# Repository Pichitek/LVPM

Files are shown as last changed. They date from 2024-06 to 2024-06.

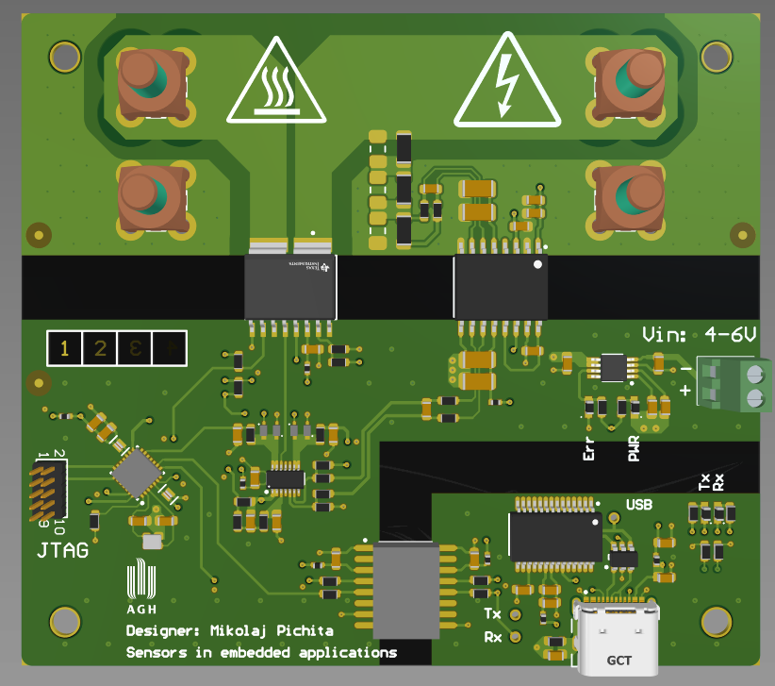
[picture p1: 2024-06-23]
photos/3D.png

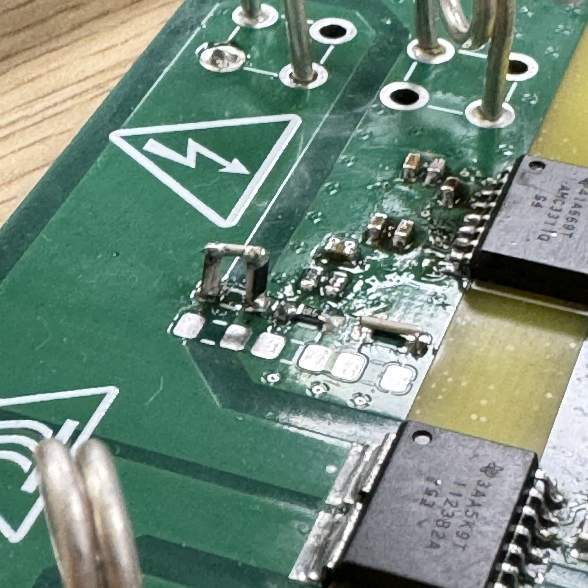
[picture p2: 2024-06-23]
photos/poprawiony_dzilnik.jpg

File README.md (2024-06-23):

# Low Voltage Power Measurement
Premise of the project for this class was to implement any sensor into working device. Our group decided that we would like to make power measurement device based on widely available Hall sensors.

schemat_blokowy

As seen on this block diagram, this project can serve as standalone device. It is capable of measuring current and voltage, acquiring data on STM32F0 microcontroller and transmitting this data over UART. Design provides two isolation barriers to make sure that any device which is connected to the LVMP will not be damaged.

This project consists of:
- PCB and schematic of LVPM
- firmware for the microcontoller
- desktop app for data visualization (https://github.com/arkadiuszrapacz/HalSensorApp)
- project presentations and report (written in polish)

zmonotwana_plyka

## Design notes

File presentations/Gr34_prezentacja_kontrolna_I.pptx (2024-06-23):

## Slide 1

Miernik mocy do zastosowań LV

Grupa nr 34: Paweł Pasierbek, Mikołaj Pichita, Arkadiusz Rapacz,
Tomasz Szydłak

18.03.2024

## Schemat blokowy

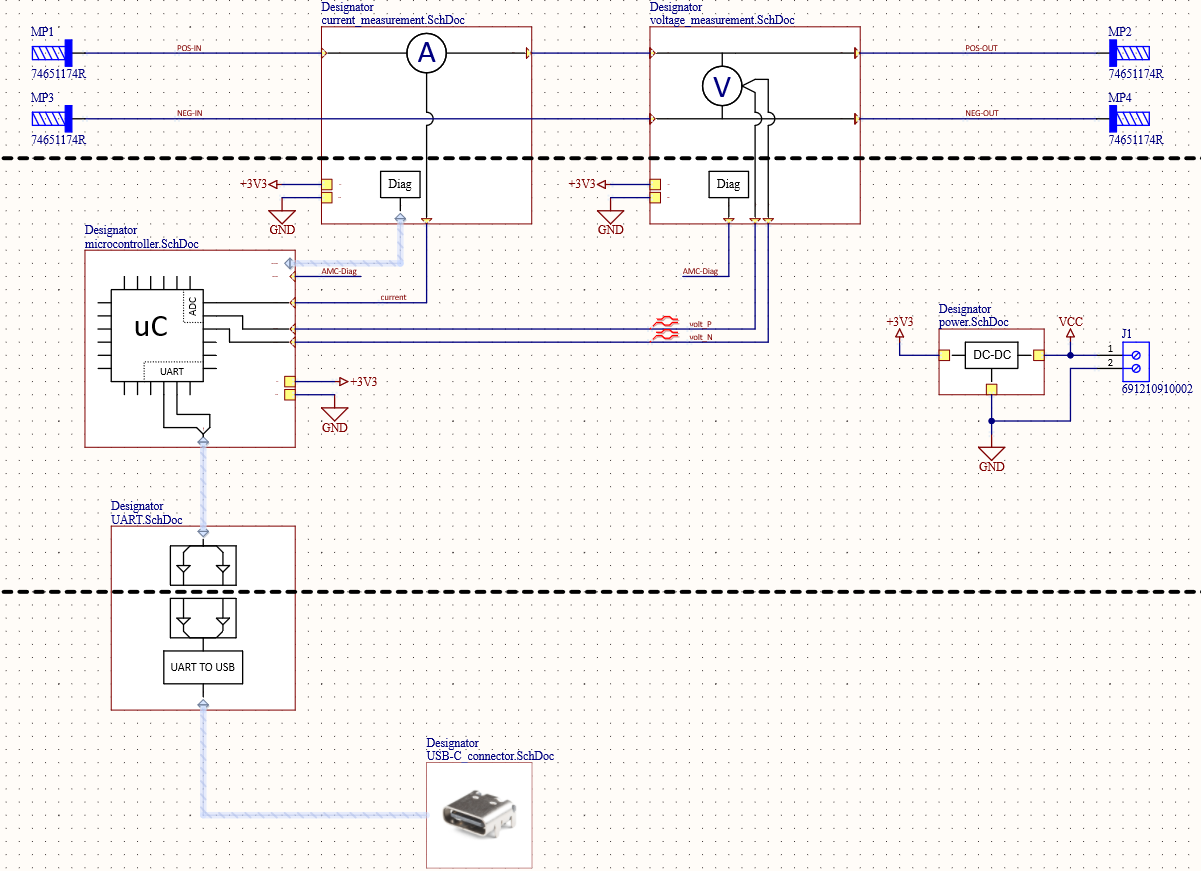
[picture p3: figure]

MIKOŁAJ

Rys. 1) Schemat blokowy

## Działanie sensora Halla

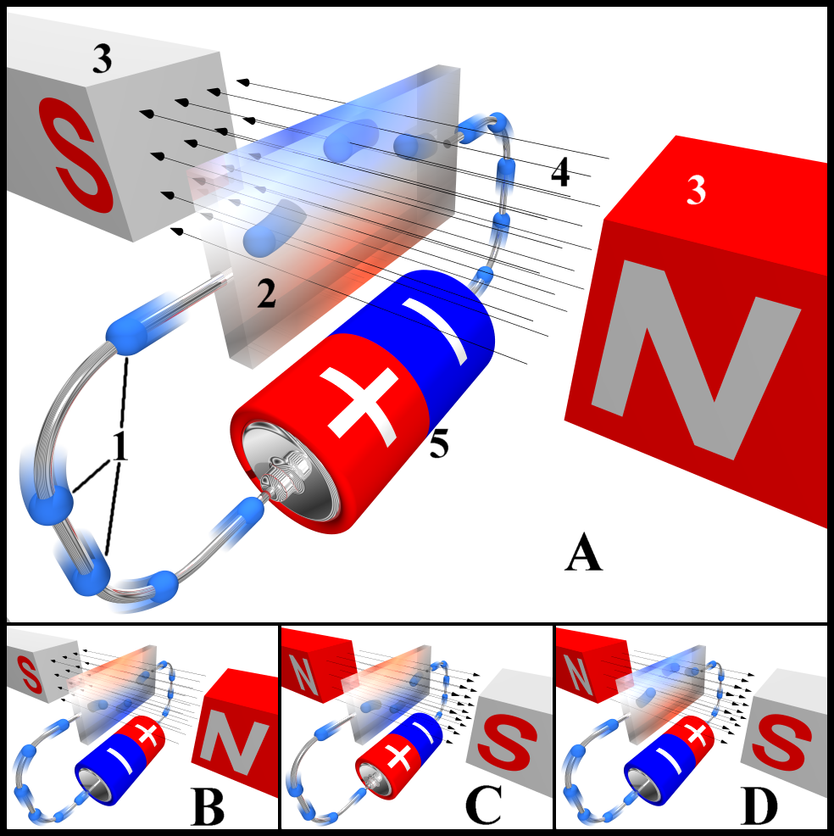
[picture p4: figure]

Rys. 2) Zobrazowanie efektu Halla

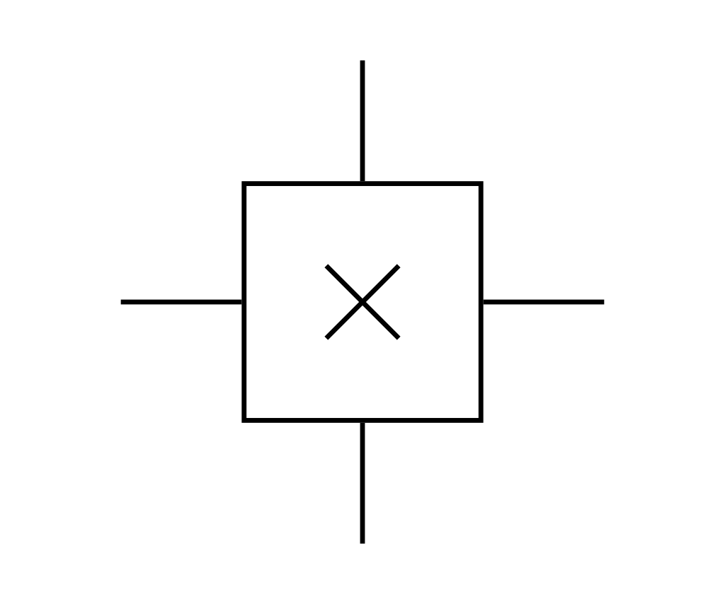
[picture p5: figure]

Rys. 3) Symbol hallotronu

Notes: Zjawisko polegające na wystąpieniu różnicy potencjałów w przewodniku, w którym płynie prąd elektryczny, gdy przewodnik znajduje się w poprzecznym do płynącego prądu polu magnetycznym. Ta różnica potencjałów, zwana napięciem Halla, pojawia się między płaszczyznami ograniczającymi przewodnik, prostopadle do płaszczyzny wyznaczanej przez kierunek prądu i wektor indukcji magnectycznej. Jest ona spowodowana działaniem siły Lorentza na ładunki poruszające się w polu magnetycznym.

## Sensor TMCS1123

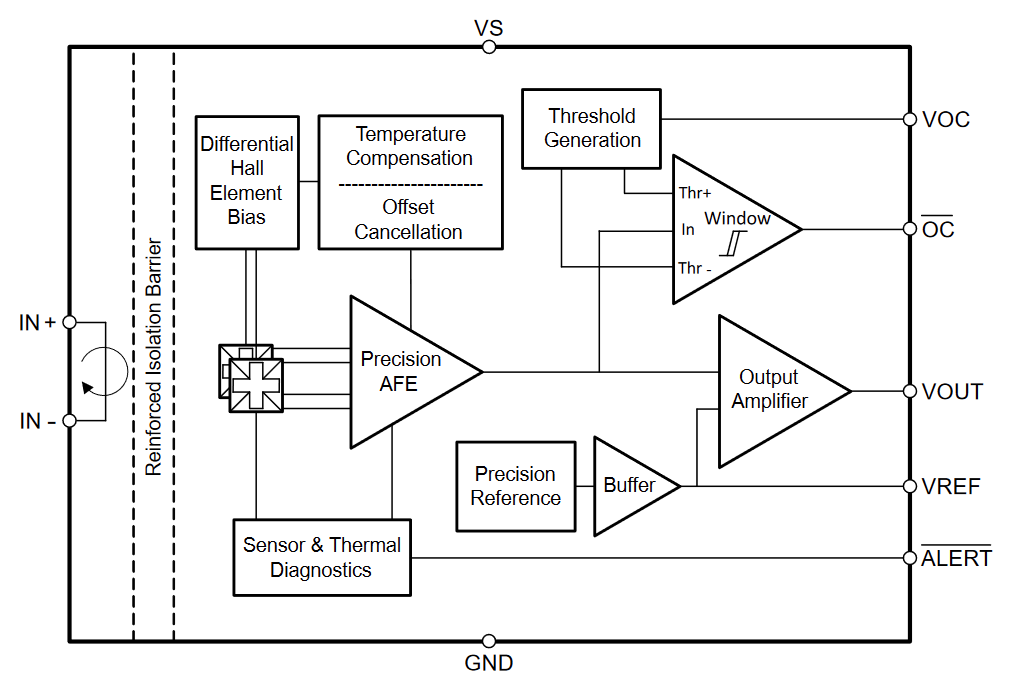
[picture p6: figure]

Rys. 4) Diagram funkcyjny sensora TMCS

## Zastosowanie mikroprocesora

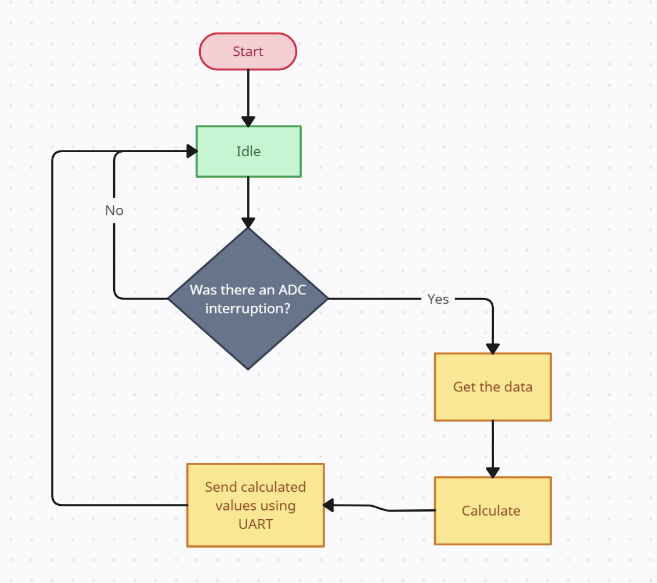
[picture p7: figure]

Rys. 5) Diagram blokowy przedstawiający działanie aplikacji

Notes: tuaj jakis flowchart jak bedzie działa uC w projekcie: idle -> przerwanie od ADC -> akwizycja danych -> obliczenie -> transmisja po UART

## Aplikacja na urządzenia stacjonarne

Dane do aplikacji dostarczane będą za pomocą protokołu UART.
Aplikacja służyć będzie do monitorowania wskazań wykorzystanego czujnika, a jej głównym założeniem w procesie realizacji będzie prostota obsługi oraz przejrzystość przedstawianych danych.

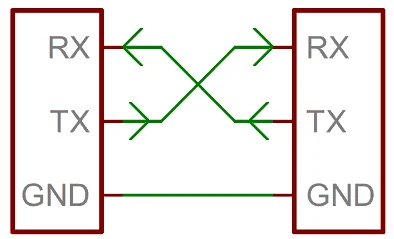
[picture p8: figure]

Rys. 6) Uproszczona wizualizacja protokołu komunikacyjnego UART

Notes: tutaj idk, nawet coś w paint naszkicowane jak ta apka będzie wyglądać POGLĄDOWO, ja bym dał 2 odczyty z ADC (prąd napięcie) wyliczana moc, wykres mocy w czasie który się będzie updateował, i jakieś dla diagnostyki informacje tymu: SENSOR GOOD na zielono

## Zakres odpowiedzialności w zespole

- Arek: Aplikacja służąca do parsowania danych na PC wraz z przejrzystym GUI
- Mikołaj: design systemu, projekt PCB, montaż, testowanie
- Tomek i Paweł: Programowanie mikroprocesora, obsługa sensorów, transfer danych na PC

## Dziękujemy za uwagę

## Bibliografia

Rys. 2) https://pl.wikipedia.org/wiki/Zjawisko_Halla#/media/Plik:Hall_effect.png
Rys. 3) https://pl.wikipedia.org/wiki/Hallotron#/media/Plik:Common_Hall_Sensor_Symbol.svg
Rys. 4) https://www.ti.com/lit/ds/symlink/tmcs1123.pdf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
Rys. 6) https://cdn.forbot.pl/blog/wp-content/uploads/2016/03/KursF4_7_25.png

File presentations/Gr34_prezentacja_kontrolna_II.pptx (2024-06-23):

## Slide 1

Miernik mocy do zastosowań LV

Grupa nr 34: Paweł Pasierbek, Mikołaj Pichita, Arkadiusz Rapacz,
Tomasz Szydłak

18.03.2024

## Schemat elektryczny

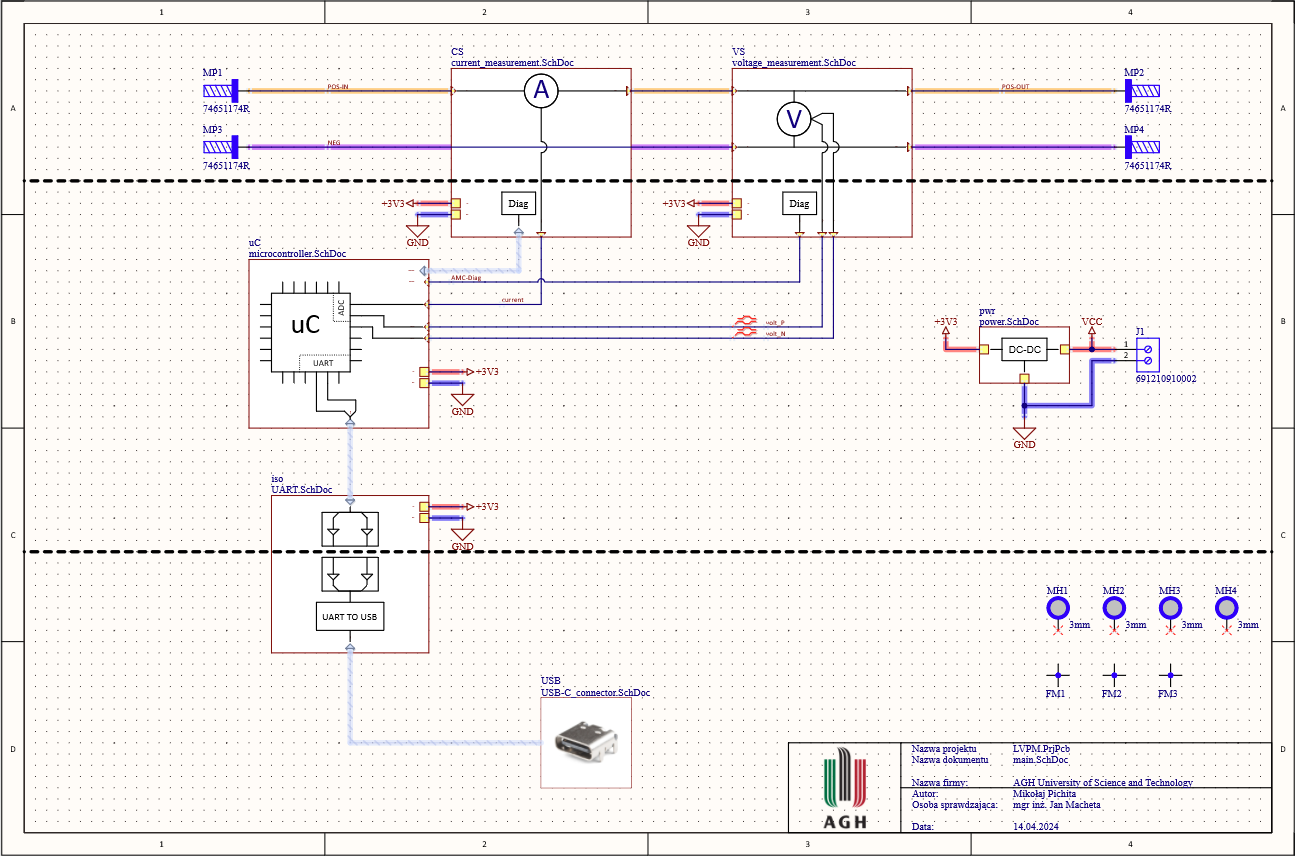
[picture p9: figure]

Rys. 1) Schemat blokowy

## Schemat elektryczny - pomiar prądu

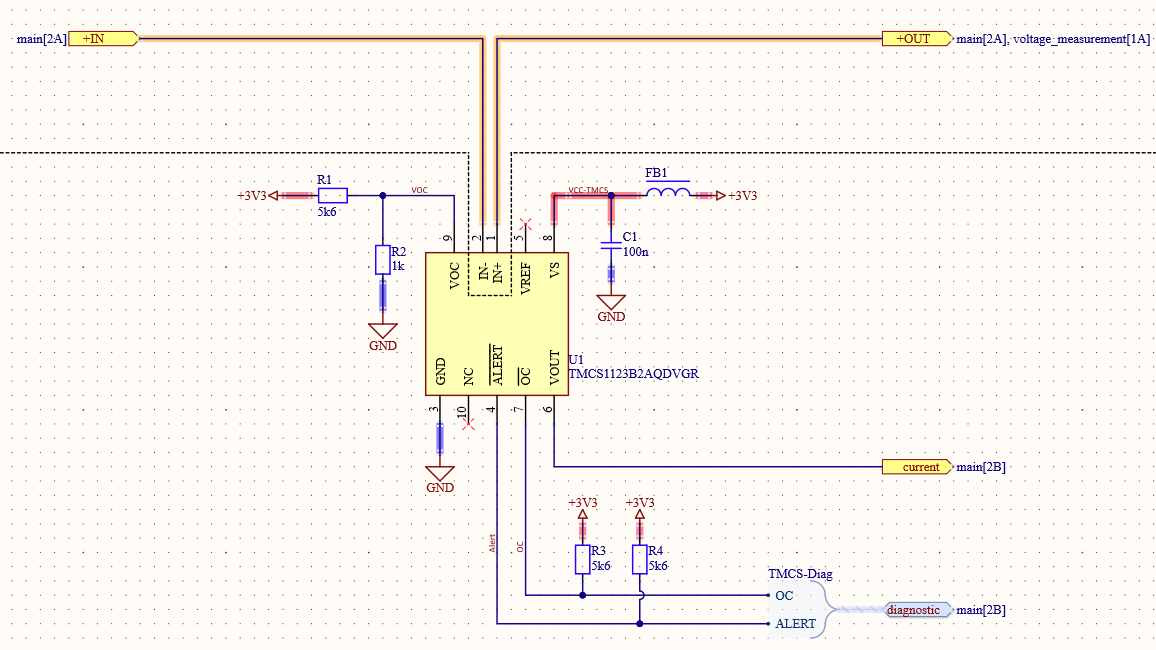
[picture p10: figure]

Rys. 2) Pomiar prądu wykorzystujący sensor Halla

## Schemat elektryczny - pomiar napięcia

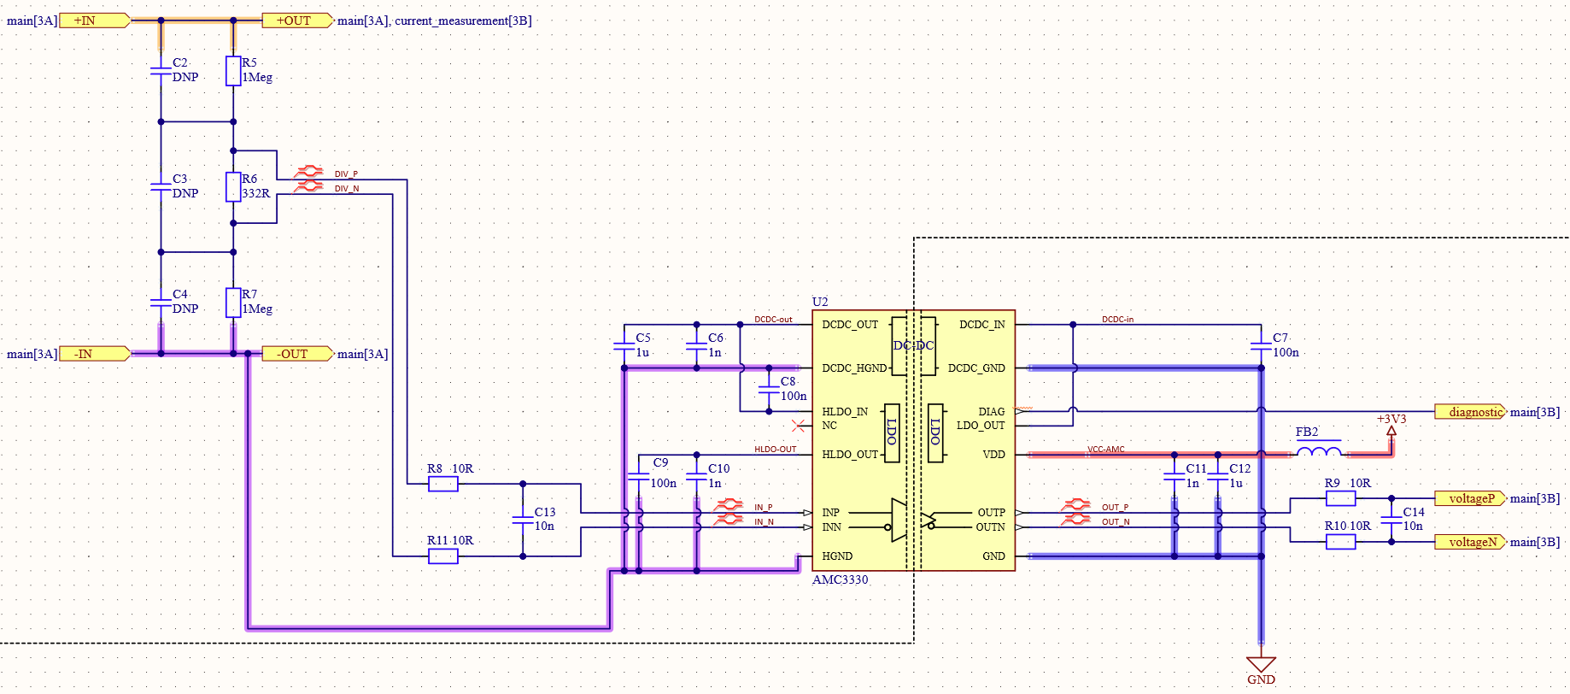
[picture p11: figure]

Rys. 3) Pomiar napięcia na izolowanym wzmacniaczu

## Płytka PCB

Rys. 4) Render 3D płytki PCB

## Płytka PCB

## Płytka PCB

## Płytka PCB

## Płytka PCB

## Oprogramowanie na mikrokontroler

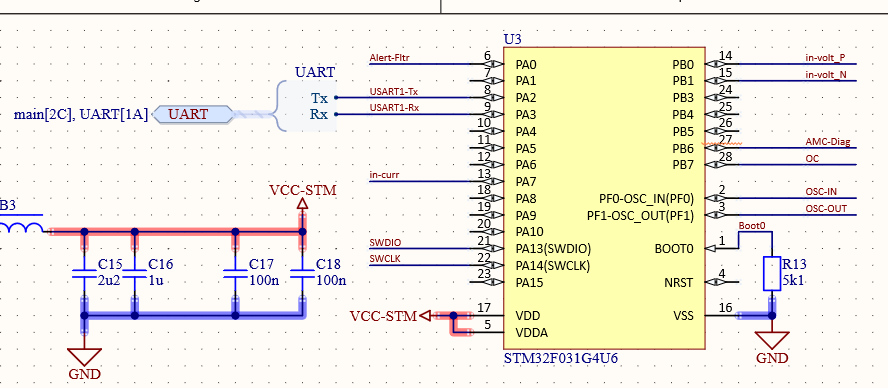
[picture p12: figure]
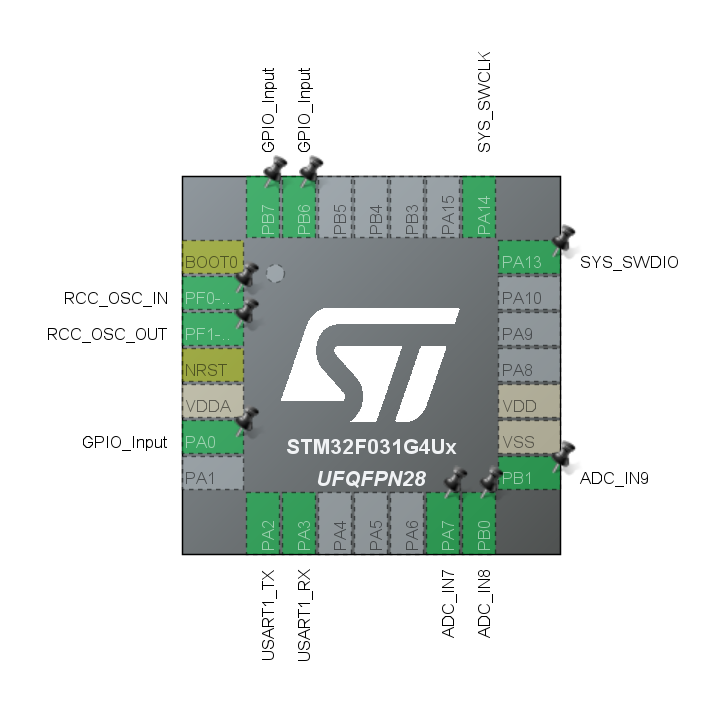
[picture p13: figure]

- in-curr - wejście analogowe do pomiaru prądu
- in-volt_P, in-volt_N - wejścia analogowe do pomiaru napięcia
- SWDIO, SWCLK - wejścia do programowania
- OSC-IN, OSC-OUT - wejścia do podłączenia oscylatora
- Alert-Fltr, OC, AMC-Diag - wejścia GPIO

## Aplikacja na urządzenia stacjonarne

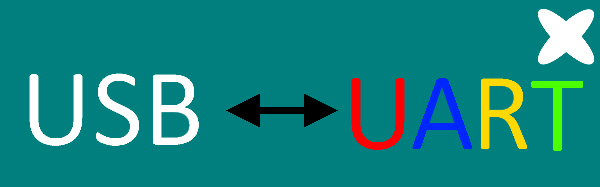
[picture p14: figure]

Język programowania: Python
Dodatkowe biblioteki: PySerial / PyQt5
Komunikacja: UART
Funkcjonalność: Przedstawienie odczytów z sensora Halla
Dodatkowo: Wizualizacja danych w czasie (wykres)

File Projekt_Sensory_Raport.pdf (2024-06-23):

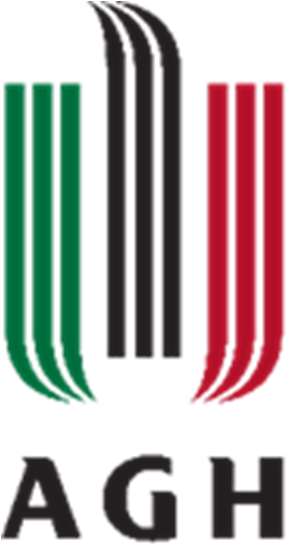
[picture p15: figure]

# AKADEMIA GÓRNICZO-HUTNICZA

# Raport z projektu

# Miernik mocy do zastosowań LV

# z przedmiotu

# Sensory w Aplikacjach Wbudowanych

# Elektronika i Telekomunikacja - Systemy Wbudowane, rok I studiów magisterskich

# Mikołaj Pichita Arkadiusz Rapacz Tomasz Szydłak

14.06.2024r

# Spis treści

1

## 1 Opis i założenie projektu

Celem projektu jest stworzenie urządzenia będącego w stanie mierzyć moc urządzeń pracujących w zakresie napięć LV (definicja napięcia Lov Voltage to mniej niż 1500VDC lub mniej niż 1000VAC RMS). Do realizacji takiego celu wymagane są: pomiar prądu, pomiar napięcia, akwizycja danych oraz ich transmisja do celu, celem może być urządzenie sterujące lub jak w naszym przypadku komputer osobisty.

### 1.1 Założenia projektowe i wysokopoziomowy opis projektu

Założenia projektowe odnośnie warstwy sprzętowej

- Pomiar prądu realizowany przy pomocy sensora Halla.
- Pomiar napięcia realizowany przy pomocy izolowanego wzmacniacza operacyjnego oraz wysokoimpedancyjnego dzielnika napięcia.
- Izolacja części wysokonapięciowej do sekcji niskonapięciowej.
- Dodatkowa warstwa izolacji pomiędzy sekcją niskonapięciową a sekcją komunikacyjną.
- Komunikacja z komputerem osobistym realizowana przy pomocy protokołu USB.

Założenia projektowe odnośnie warstwy oprogramowania

- Akwizycja danych za pomocą wbudowanego przetwornika ADC w mikrokontrolera.
- Transmisja danych przy pomocy protokołu UART.
- Odczytywanie danych diagnostycznych przy pomocy pinów GPIO.
- Uśrednianie pomiarów.
- Stworzenie "pakietu" danych, który będzie łatwy do interpretacji przez aplikację na komputery osobiste.
- Stworzenie aplikacji na komputery osobiste do odczytywania danych.

### 1.2 Podział odpowiedzialności

- Mikołaj - projekt wysokopoziomowy, projekt schematu oraz PCB, montaż, testowanie
- Arkadiusz - utworzenie aplikacji desktopowej odczytującej dane na porcie szeregowym
- Tomasz - programowanie mikrokontrolera, obliczanie wartości i testy oprogramowania

## 2 Sprzęt

### 2.1 Wybór komponentów

Opis wykorzystanych komponentów oraz uzasadnienie wyboru.

2

- Sensor Halla TMCS1123 - wzmocniona izolacja na poziomie 1.3kV, szeroki zakres pomiarowy, prostota w integracji
- Izolowany wzmacniacz operacyjny AMC3330 - wzmocniona izolacja na poziomie 1.7kV, wbudowana przetwornica DC-DC, wyjście różnicowe
- Mikrokontroler STM32F0 - prosta architektura, mały footprint, 12bitowe przetworniki ADC
- Liniowy regulator napięcia LP3997 - prąd wyjścia 250mA, niskie napięcie spadkowe na regulatorze, stałe wyjście 3.3V
- Izolator cyfrowy Si8621 - duża przepustowość, dwa kanały(jeden sygnału nadającego, drugi odbierającego), możliwość zasilenia zarówno 3.3V jak i 5V
- Konwerter UART→USB FT232 - standardowe rozwiązanie w przemyśle
- Wzmacniacz operacyjny TLV9004 - mały footprint, cztery kanały

Pozostałe komponenty wykorzystane w projekcie są elementami pasywnymi. W przypadku doboru rezystorów zwracano uwagę na dokładność rezystancji w kluczowych elementach, takich jak dzielniki napięcia, oraz na maksymalną moc jaką w stanie są one wytrzymać. Kondensatory dobierano tak aby klasyfikacja napięciowa danego kondensatora była co najmniej dwukrotnie większa od spodziewanego napięcia w danym węźle. Dodatkowo przy mikrokontrolerze zastosowano kondensatory w obudowie 0204 minimalizując impedancję pasożytniczą elementu.

3

### 2.2 Opis schematu

Projekt płytki PCB został wykonany w programie Altium Designer 24.

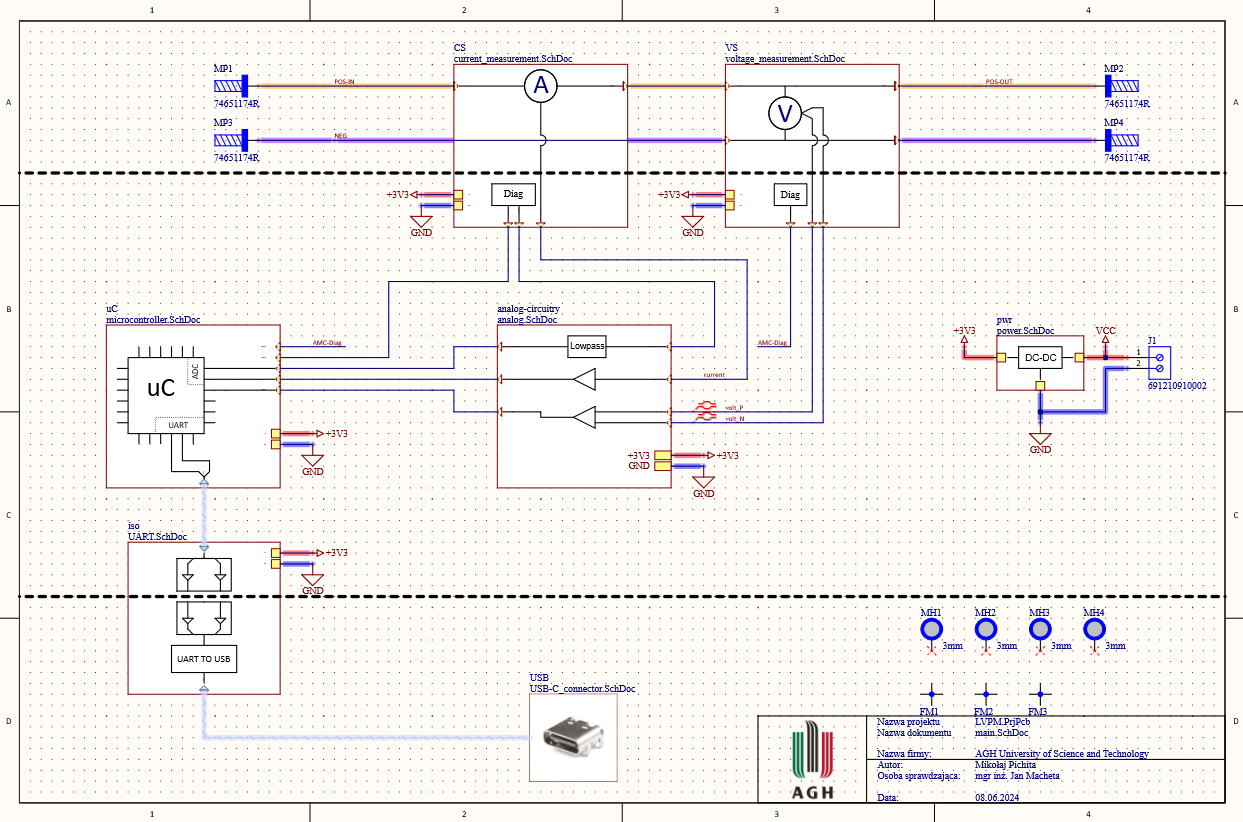
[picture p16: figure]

Rysunek 1: Schemat blokowy urządzenia po zaimplementowanych poprawkach

Schemat blokowy składa się łącznie z siedmiu bloków funkcyjnych:

- pomiar prądu
- pomiar napięcia
- front-end analogowy dla sygnałów pochodzących z sensorów
- mikrokontroler
- izolator cyfrowy i konwerter UART→USB
- złącze USB-C
- zasilanie

4

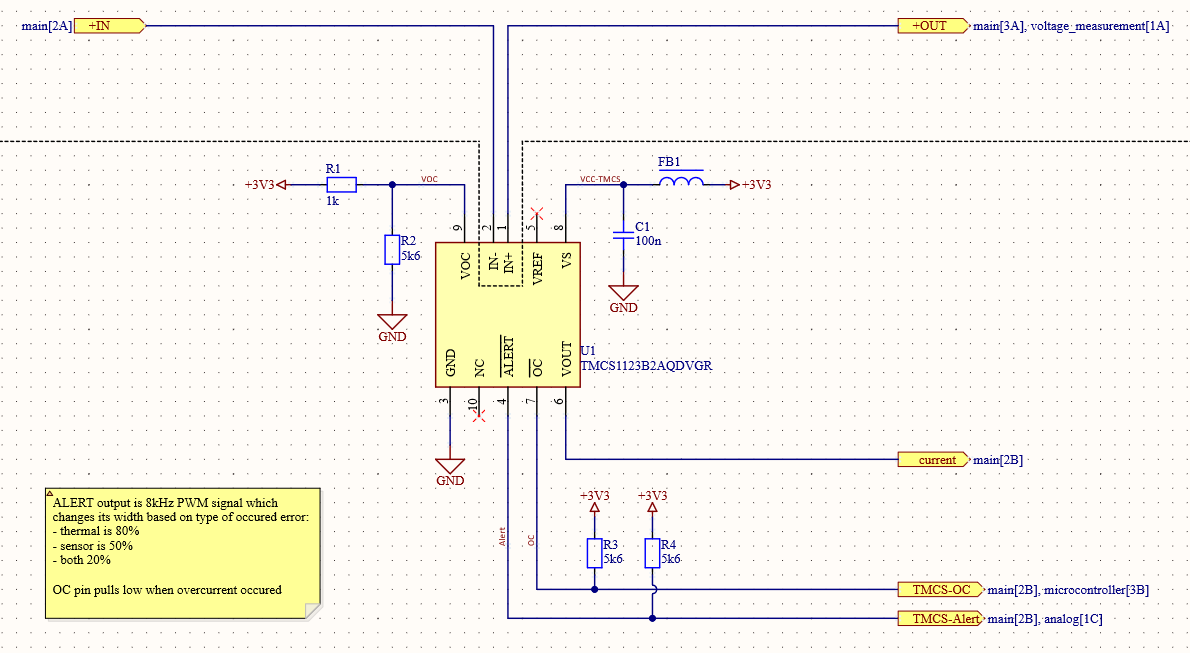
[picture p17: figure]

Rysunek 2: Fragment schematu zawierający układ odpowiedzialny za pomiar prądu

Wykorzystywany układ, TMCS1123, oprócz samego sensora Halla zawiera również kilka interesujących modułów. Sensor posiada układ diagnostyczny, kompensację temperatury, kompensację wpływu zewnętrznych zakłóceń w postaci pola magnetycznego oraz wyjście cyfrowe informujące o przekroczeniu zadanego limitu prądowego. Układ scalony jest produkowany w kilku wersjach, różnią się one możliwym zakresem mierzonego prądu. Wybrana wersja jest w stanie mierzyć prąd od -30A do +30A. Dodatkowo, przy pomocy dzielnika napięcia, została ustawiona wcześniej wspomniana wartość przekroczenia limitu prądowego. Sensor będzie zwracał dodatkowo informację o zbliżaniu się ustalonego progu zmieniając stan logiczny pinu OC. Wartość została ustawiona na 16.7A.

5

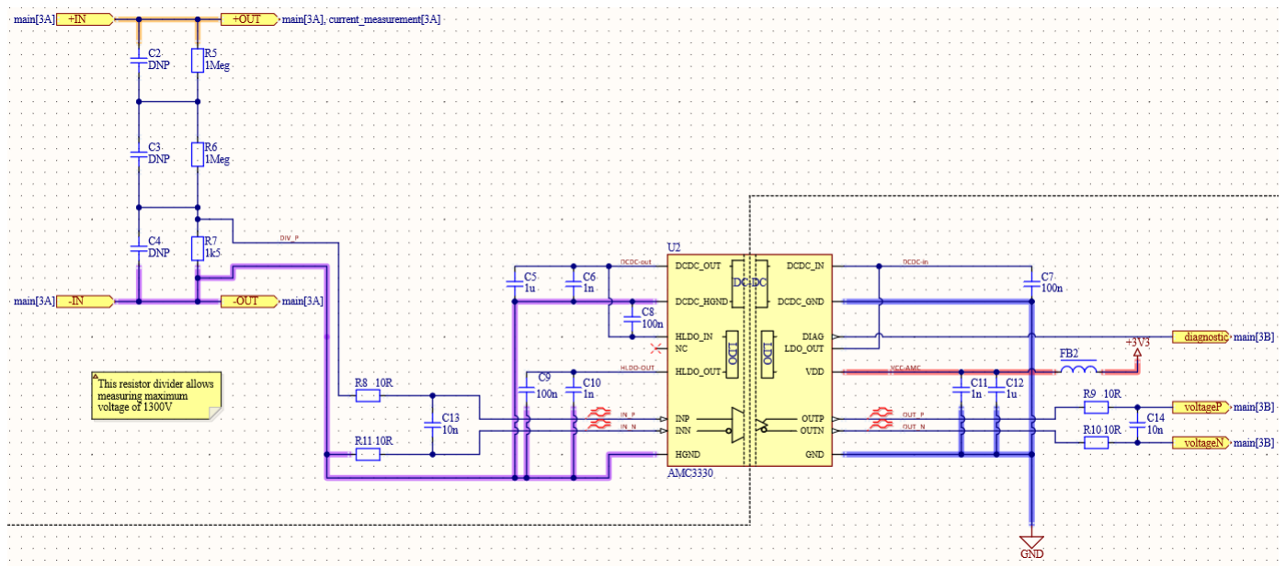
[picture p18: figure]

Rysunek 3: Fragment schematu zawierający układ odpowiedzialny za pomiar napięcia

Izolowany wzmacniacz operacyjny AMC3330 posiada wbudowaną przetwornicę DC-DC. Dodatkowo, układ posiada wbudowany moduł diagnostyczny moniturujący zachowanie wbudowanej przetwornicy. Maksymalne napięcie różnicowe jakie można podać między wejścia układu to +- 1V. Mając to na uwadze, dzielnik napięcia został dobrany w taki sposób aby zmaksymalizować zakres napięcia na rezystorze pomiarowym. Maksymalna wartość mierzonego napięcia wynosi 1300VDC.

### 2.3 PCB

Najważniejszą rzeczą w trakcie projektowania było zachowanie odstępów zapewniających izolację, zarówno sensor TMCS jak i wzmacniacz AMC w pewien sposób zdefiniowały szerokość odstępu między częścią mocy a częścią niskonapięciową. W trakcie testów do urządzenia pomiarowego został podłączony komputer osobisty i aby uniknąć uszkodzenia sprzętu, wykorzystano dodatkowy izolator cyfrowy.

6

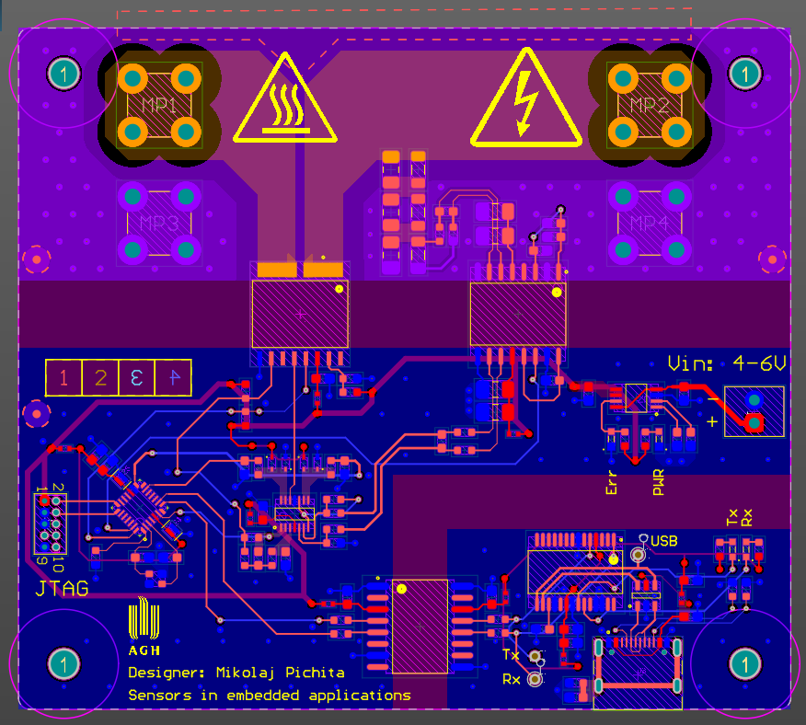
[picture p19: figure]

Rysunek 4: Widok 2D miernika mocy

Płytka posiada cztery warstwy gdzie dwie wewnętrzne służą jako poligony odniesienia dla sygnałów znajdujących się na warstwach Top i Bottom. Częstą praktyką jest umieszczanie na PCB okienek wskazujących daną warstwę płytki. Pozwala to na pewne ubezpieczenie, które zmniejsza szansę, że wykonawca płytki nie pomyli warstw miedzi. Na płycie zamieszczono 3 punkty fiducial marker. Wymiary płytki to 85x75mm.

7


Rysunek 5: Widok 2D miernika mocy

## 3 Oprogramowanie

### 3.1 Omówienie oprogramowania mikrokontrolera

Oprogramowanie na mikrokontroler powstawało w dwóch etapach. Pierwszy etap polegał na stworzeniu działającego programu na płytkę ewaluacyjną STM32F407, drugi zaś na przeniesieniu kodu na użyty w projekcie mikrokontroler STM32F0. Oba mikrokontrolery są z tej samej rodziny, więc w założeniu takie działanie miało na celu przyspieszenie stworzenia projektu (kod mógłby powstawać zanim płytka zostałaby złożona).
Pierwszy etap zawierał w sobie zebranie wymagań, jakie mikrokontroler miał spełniać i czynności, jakie miał wykonywać. Zawierały się w nich:
- pomiar prądu (wartość z ADC)
- pomiar napięcia (2 wartości z ADC)
- pomiar wypełnienia sygnału PWM (wykorzystywany timer)
- pomiar dwóch wartości diagnostycznych (wartości 1/0 z GPIO)
- wysyłanie danych za pomocą UART

8

Kolejnym krokiem było utworzenie projektu w programie STM32CubeIDE, wybraniu odpowiedniej płytki a następnie na zdefiniowaniu pinów, które miały zająć się określonymi zadaniami. Po wykonaniu tej czynności przystąpiono do pisania kodu, który miał się zająć kolejnymi problemami. Pomiary, wymagające ADC, były wykonywane za pomocą pojedynczego ADC oraz trzech kanałów, jakie posiadał. Wykorzystany był tylko jeden ADC, ponieważ docelowy mikrokontroler posiadał tylko jeden taki moduł. Kanały zostały wykorzystane jako sposób szybkiego odczytywania informacji z kilku wejść. Wszystkie pomiary były wykonywane za pomocą DMA (Direct Memory Access), żeby uniknąć niepotrzebnego obciążania kontrolera. Po wykonaniu trzech odczytów z trzech kanałów wykonywane było przerwanie, za pomocą którego obliczano wartości prądu i napięcia, średnią prądu i napięcia z wielu pomiarów, a także wysyłano dane za pomocą UART.
Prąd był mierzony za pomocą pojedynczego kanału ADC, a jego odczytywana wartość była obliczana na wartość w mA×100, żeby uniknąć wykonywania obliczeń na liczbach zmiennoprzecinkowych.
I = (CurrentAV R · 3300 · 100 4096
− 165000) · 20 | (1)

Gdzie:

- CurrentAV R - średnia wartość z ostatnich 10 pomiarów prądu

Reszta wartości stałych została dobrana tak, żeby z 12 bitowej wartości otrzymać prawdziwą wartość prądu. Uwzględniono offset na elemencie, który pozwala na pomiar prądu dodatniego jak i ujemnego.
Napięcie było mierzone różnicowo za pomocą dwóch kanałów ADC, odejmowane od siebie w celu usunięcia offsetu, a następnie jego wartość zostawała odczytana (w mV×10, żeby uniknąć wykonywania obliczeń na liczbach zmiennoprzecinkowych).

V =

V oltageAV R · 33 · 3012
4096

(2)

Gdzie:

- V oltageAV R - średnia wartość z ostatnich 10 pomiarów prądu

Reszta wartości stałych została dobrana tak, żeby z 12 bitowej wartości otrzymać prawdziwą wartość napięcia. Uwzględniono offset na elemencie poprzez odjęcie różnicowo dwóch wartości wejściowych. Wartości liczbowe przystosowane były do założenia, że rezystor pomiarowy na dzielniku napięcia będzie miał 332Ω. W finalnej wersji kodu wartości zostały odpowiednio zmienione, żeby obejmowały one nowy rezystor o wartości 1500Ω.
PWM był mierzony za pomocą opcji "PWM input" dostępnej dla połączonych kanałów dla timera. Pozwalało to na szybkie mierzenie sygnału za pomocą pojedynczego wejścia na mikrokontrolerze. Dwie wartości diagnostyczne, które mogły osiągać jedynie stan wysoki lub niski były odczytywane za pomocą wejść GPIO. Ustawione był przerwania, które sprawiały, że w sytuacji kiedy wejście weszłoby w przeciwny stan byłoby to wpisywane do odpowiedniej zmiennej a następnie wysyłane przez UART.
Drugi etap programowania to było przeniesienie kodu na wykorzystany na płytce mikrokontroler STM32F0. Moduły dostępne na STM32F407 nie były w większości kompatybilne z STM32F0 i zostały zamienione. Lista wymagań i rozwiązań na tym mikrokontrolerze wygląda następująco:
- pomiar prądu (wartość z ADC)
- pomiar napięcia (wartość z ADC)

9

- pomiar wypełnienia sygnały PWM (wartość z ADC)
- pomiar dwóch wartości diagnostycznych (wartości 1/0 z GPIO)
- wysyłanie danych za pomocą UART

Prąd był mierzony za pomocą ADC, a jego odczytywana wartość była obliczana na wartość w mA×100, żeby uniknąć wykonywania obliczeń na liczbach zmiennoprzecinkowych.

avg_c = (avg_c · 0.6) + (raw_c · 0.4) | (3)

I = (avg_c · 3300 · 100
4096
− 165000) · 20 | (4)

Gdzie:

- avg_c - średnia wartość prądu, obliczana w sposób wykładniczy
- raw_c - dane pobierane z przetwornika

Reszta wartości stałych została dobrana tak, żeby z 12 bitowej wartości otrzymać prawdziwą wartość prądu. Uwzględniono offset na elemencie, który pozwala na pomiar prądu dodatniego jak i ujemnego.
Napięcie było mierzone za pomocą ADC. Różnicowe odejmowanie zostało już wykonane w układzie za pomocą wzmacniacza operacyjnego, więc jedyne co zostało to pomiar wartości. Odczytywana wartość była obliczana na wartość w mV×10, żeby uniknąć wykonywania obliczeń na liczbach zmiennoprzecinkowych.
avg_v = (avg_v · 0.6) + (raw_v · 0.4) | (5)

V =

avg_v · 33 · 668 · 2
4096

(6)

Gdzie:

- avg_v - średnia wartość napięcia, obliczana w sposób wykładniczy
- raw_v - dane pobierane z przetwornika

Reszta wartości stałych została dobrana tak, żeby z 12 bitowej wartości otrzymać prawdziwą wartość napięcia. Wartości liczbowe zostały zmienione, żeby uwzględnić zmianę rezystora w dzielniku napięcia na taki o wartości 1500Ω.
Wypełnienie sygnału PWM było mierzone za pomocą ADC. Na płytce został utworzony układ filtrujący. Na jego wyjściu można odczytać stałą wartość napięcia, która zmienia się wraz z wartością wypełnienia. 0% wypełnienia to 0V, 50% wypełnienia to 1.65V, a 100% wypełnienia to 3.3V czyli logiczne 1.
Dwie wartości diagnostyczne, które mogły osiągać jedynie stan wysoki lub niski były odczytywane za pomocą wejść GPIO. Wejścia te odczytywały wartości tych pinów i na bieżąco wysyłały za pomocą UART.
Przy przesyłaniu wiadomości protokołem UART uzgodniono pewien format, dzięki któremu aplikacja uruchomiona na komputerze osobistym będzie w stanie poprawnie zidentyfikować wysyłane do niej informacje. Wysyłanymi informacjami są: to dwa 32-bitowe inty przekazujące wartości napięcia oraz prądu wraz ze znakami a także 3 16-bitowe inty, za pomocą których przekazywane były sygnały diagnostyczne i współczynnik wypełnienia PWM przerobiony na wartość analogową. Te dane rozdzielono średnikami i wysyłano cały czas w tej samej kolejności.

10

### 3.2 Aplikacja desktopowa do wyświetlania danych z sensora

Proces realizacji aplikacji desktopowej służącej do wyświetlania danych otrzymywanych na konkretnym porcie szeregowym rozpoczęty został od przygotowania środowiska programistycznego oraz zainstalowania odpowiednich bibliotek zewnętrznych.

Przygotowanie środowiska programistycznego

Aplikację desktopową służącą do wyświetlania danych otrzymanych z naszego skonstruowanego urządzenia zdecydowano się napisać korzystając z języka programistycznego ’Python’, wykorzystując dodatkowo biblioteki takie jak: PyQt5 do tworzenia interfejsów graficznych oraz PySerial w celu zapewnienia dostępu do danych otrzymywanych na porcie szeregowym.
W celu umożliwienia uruchomienia aplikacji na jednostkach bez zainstalowanego Pythona oraz wykorzystanych bibliotek, zastosowano narzędzie ’PyInstaller’ do stworzenia samodzielnego pliku wykonywalnego AppSensor.exe. Podczas procesu budowania, ustawiono flagi –onefile - wszystkie zależności oraz pliki pakowane są w jeden plik wykonywalny oraz –windowed - tworzenie aplikacji z interfejsem GUI bez konsoli.

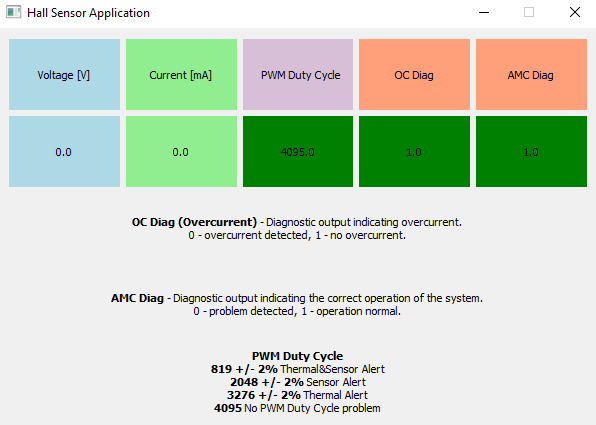
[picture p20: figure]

Rysunek 6: Okno aplikacji pomiarowej

11

Kod źródłowy aplikacji desktopowej

- Wyszukiwanie sensora
Na potrzebny projektu napisano funkcję sprawdzającą listę dostępnych urządzeń podłączonych do jednostki przez port szeregowy USB. Funkcja ta wyszukuje urządzenie o nazwie ’USB Serial Port’ (nazwa naszego urządzenia). W przypadku, gdy funkcja znajdzie urządzenie o takiej nazwie, zwraca numer portu szeregowego, do którego owe urządzenie jest podłączone, natomiast w przypadku, gdy na liście dostępnych urządzeń nie ma naszego urządzenia funkcja zwraca None.
- Inicjalizacja interfejsu użytkownika
W przypadku, gdy zostanie znalezione podłączone urządzenie o odpowiedniej nazwie, wówczas zwracany jest port szeregowy, do którego urządzenie zostało podłączone. W następnym kroku inicjowany jest interfejs użytkownika dla odpowiedniej wartości portu (’COM’ do którego podłączono sensor) oraz prędkości transmisji (baudrate).

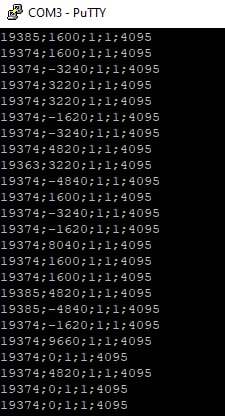
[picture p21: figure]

Rysunek 7: Otrzymywane pakiety na porcie szeregowym

12

- Pobieranie danych z portu szeregowego
Dane z sensora przesyłane są z wykorzystaniem protokołu komunikacyjnego UART na port szeregowy jednostki komputerowej. Przesyłane pakiety danych zostały zaprezentowane na rysunku 7. Jest to pięć wartości oddzielonych średnikiem, odpowiednio; napięcie, natężenie prądu, flaga diagnostyczna dotycząca przeciążenia prądowego, flaga diagnostyczna informująca o poprawnym działaniu urządzenia, wartość wypełnienia PWM. Prewencyjnie otrzymane dane są dekodowane dzięki wykorzystaniu ’UTF-8’, usuwane są białe znaki, a następnie pakiet jest separowany na pięć wartości oddzielonych od siebie średnikiem. Wartości te wpisywane są do tablicy, z której następnie są pobierane w celu reprezentacji poszczególnych wartości.
- Aktualizowanie wyświetlanych danych W celu zapewnienia responsywności oraz stabilności aplikacji, zastosowano QTimer. Dzięki wykorzystanemu timerowi aplikacja może periodycznie wykonywać funkcje bez blokowania głównego wątku, co zapobiega możliwemu zawieszaniu się aplikacji przez wzgląd na wysokie zużycie procesora. Kolejnym plusem takiego rozwiązania jest przejrzystość interfejsu graficznego, prezentując użytkownikowi najnowsze dane, bez opóźnień.

Interfejs graficzny składa się z pięciu pól prezentujących odpowiednio podpisane wartości. Wyjaśnienie wskazań indykatorów odpowiedzialnych za flagi diagnostyczne zostało umieszczone wraz z wyjaśnieniem możliwych błędów dotyczących wartości wypełnienia PWM na samym dole aplikacji okienkowej.

## 4 Uruchomienie

Po zebraniu wszystkich zamówionych części oraz otrzymaniu płytki PCB przystąpiono do procesu montażu. Dzięki umieszczeniu wszystkich komponentów na górnej warstwie odbyło się to bez większych problemów. Takie umieszczenie komponentów przyda się w późniejszym debugowaniu warstwy sprzętowej. W trakcie montażu zauważono pierwsze drobne błędy jakie popełniono w trakcie projektowania płytki: footprint udostępniony przez producenta diod schottkyego nie nadawał się do ręcznego montażu, przy złączu zasilającym płytkę umieszczono, na warstwie silkscreen, znaki pozwalające rozróżnić polaryzację zasilania - jak się okazało rozmieszczono je błędnie, polaryzacja diod LED została obrócona. Co prawda są to głównie błędy kosmetyczne, nie zakłócają one w żadnym stopniu pracy płytki ale należy je odnotować.

13

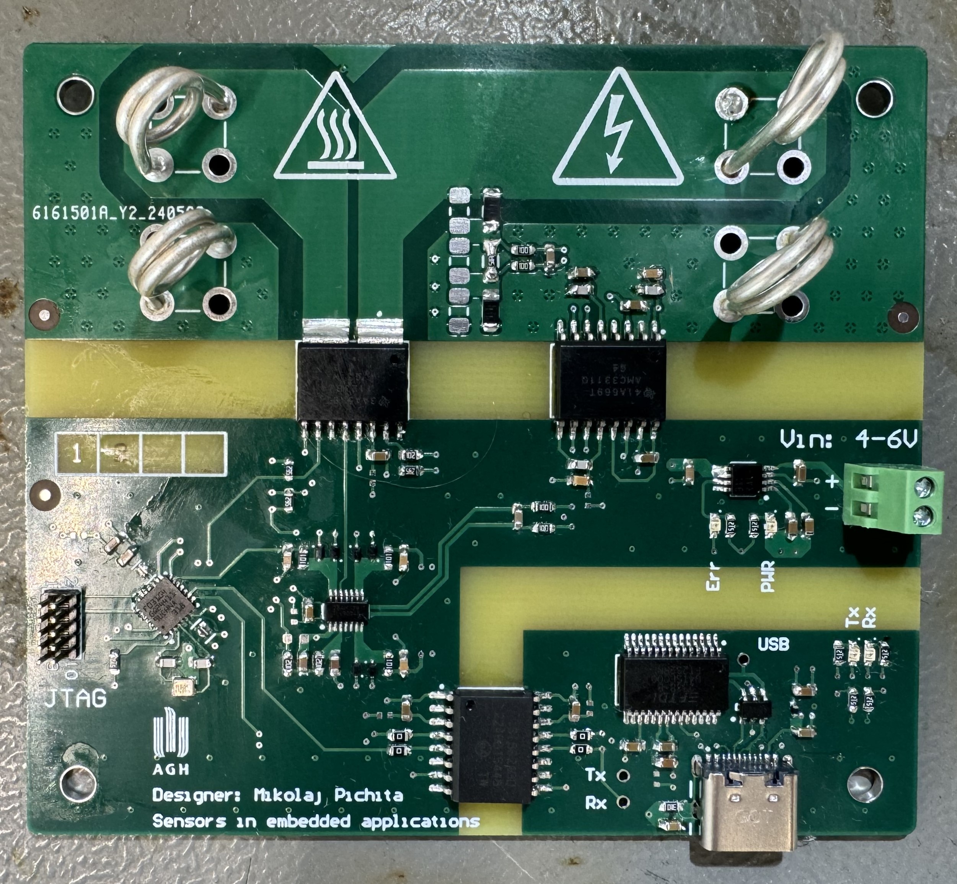
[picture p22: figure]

Rysunek 8: Zmontowana płytka miernika

Przed testami wysokonapięciowymi przeprowadzono testy funkcjonalne płytki. Kontroler bez problemu można było zaprogramować, transmisja po UART działa poprawnie - urządzenie po podpięciu do komputera jest wykrywane jako urządzenie szeregowe i da się zaobserwować przychodzące komunikaty, odczyt z kanałów ADC działa - wartości są wyświetlana na porcie szeregowym. Niepokojącą informacją był odczyt z kanałów dotyczących pomiaru napięcia. Na parze różnicowej odczytywano wartości, które nie były zgodne z wartościami otrzymanymi w symulacjach i opisanymi w datasheecie. Jak się okazało, został popełniony błąd przy projektowaniu bloku pomiaru napięcia. Fragment schematu widoczny na rysunku 3 jest poprawiony. Przed tym, rezystor pomiarowy był umieszczony między dwoma innymi rezystorami, a nie tak jak teraz - między rezystorem a potencjałem NEG. Po wprowadzeniu poprawki na PCB, odczytywane wartości zgadzały się z notą katalogową.

14

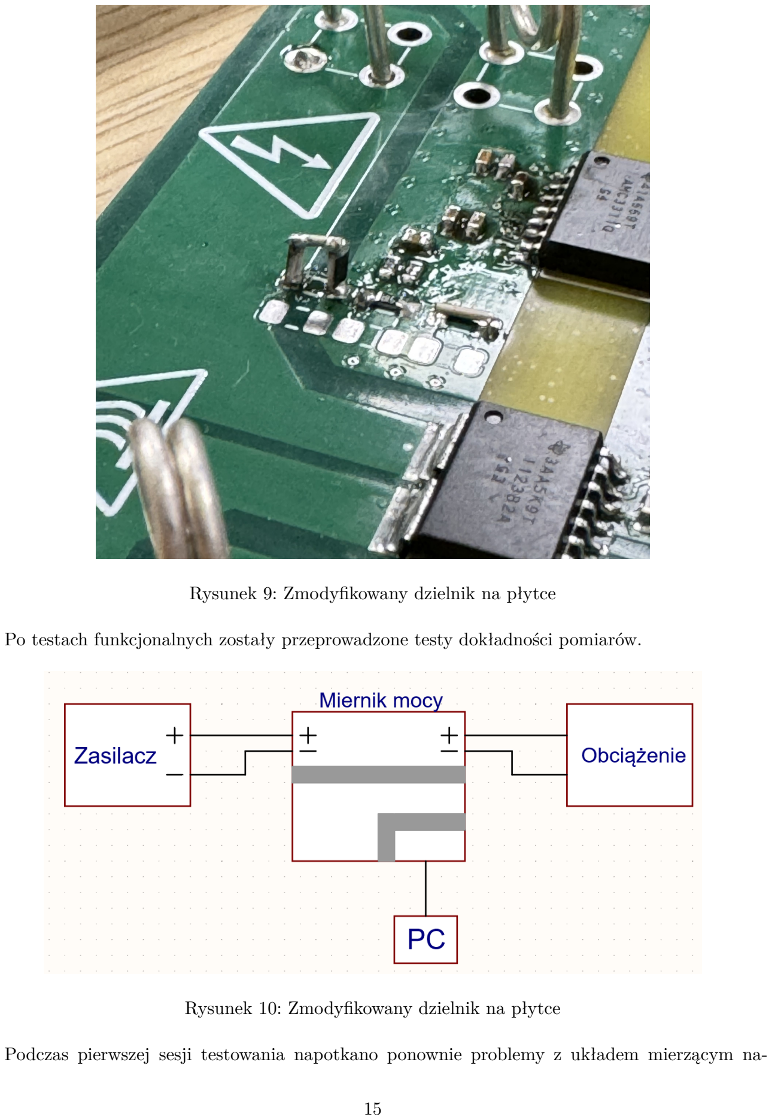
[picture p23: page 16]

Rysunek 9: Zmodyfikowany dzielnik na płytce

Po testach funkcjonalnych zostały przeprowadzone testy dokładności pomiarów.

Rysunek 10: Zmodyfikowany dzielnik na płytce

Podczas pierwszej sesji testowania napotkano ponownie problemy z układem mierzącym na-

15 pięcie. Zwracana wartość nie była w żadnym skorelowana z napięciem zasilacza. Płytka została zaprojektowana z myślą o wykorzystaniu różnicowych przetworników ADC, jak się okazało, zamówiony mikrokontroler STM32F0 nie posiada różnicowego wejścia ADC. Gdy połączy się to z faktem, że wbudowana przetwornica we wzmacniaczu AMC zakłócała linie zasilającą to można zauważyć dlaczego odczyty z pomiaru napięcia były takie niedokładne. Aby zaradzić temu problemowi delikatnie zmodyfikowano płytkę PCB. Przerobiono jeden kanał układu scalonego TLV9004 tak aby nie był on buforem lecz wzmacniaczem różnicowym. Część odpowiedzialna za pomiar prądu działała poprawnie.

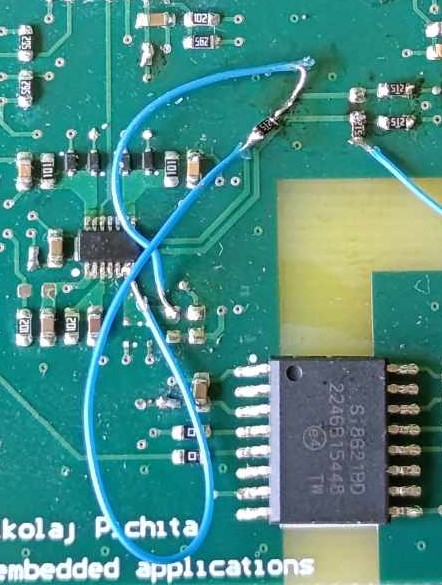
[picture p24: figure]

Rysunek 11: Bufor przerobiony na wzmacniacz różnicowy

Po zaimplementowaniu tych zmian na płycie, już w trakcie drugiej sesji, przeprowadzono pomiary dokładności układów mierzących.

Napięcie zasilacza [V] | Zmierzone napięcie [V] | Błąd [%]
100 200 300 400 500 600 700 800 840 | 105.4 204.5 304.6 403.6 503.7 602.7 701.7 800.8 840.6 | 5.4 2.25 1.53 0.9 0.74 0.45 0.24 0.1 0.07

Tabela 1: Pomiary dokładności układu mierzącego napięcie

16

Prąd zasilacza [A] | Zmierzony prąd [A] | Błąd [%]
0.620 1 2 3 3.65 5 6 7 9 | 0.634 1.007 2.022 3.021 3.663 5.009 6.026 7.044 9.021 | 2.2 0.7 1.1 0.7 0.36 0.17 0.44 0.63 0.23

Tabela 2: Pomiary dokładności układu mierzącego prąd

Błąd przy niskich wartościach prądu i napięcia jest dosyć zauważalny. W przypadku pomiaru napięcia należałoby dodatkowo skompensować niedokładne wartości rezystorów w kodzie na kontroler. Gdy mierzone wartości rosną, naturalnie można zobaczyć mniejszy błąd, który wynosi w większości pomiarów mniej niż 1%. Na tej podstawie można stwierdzić, że zaprojektowane urządzenie działa zgodnie z założeniami przedstawionymi w rozdziale 1.1.

## Bibliografia

- Nota katalogowa TMCS1123 www.ti.com/product/TMCS1123
- Nota katalogowa AMC3330 www.ti.com/product/AMC3330
- Nota katalogowa STM32F0 www.st.com/en/microcontrollers-microprocessors/stm32f031g4. html
- Nota katalogowa Si8620 www.skyworksinc.com/search?q=si8621
- Wpis na blogu www.allaboutcircuits.com/technical-articles/jtag-connectors-and-interfaces/
- Biblioteka PyQt5 https://www.riverbankcomputing.com/software/pyqt/
- Biblioteka PySerial https://github.com/pyserial/pyserial
- Narzędzie PyInstaller https://pyinstaller.org/en/stable/

17

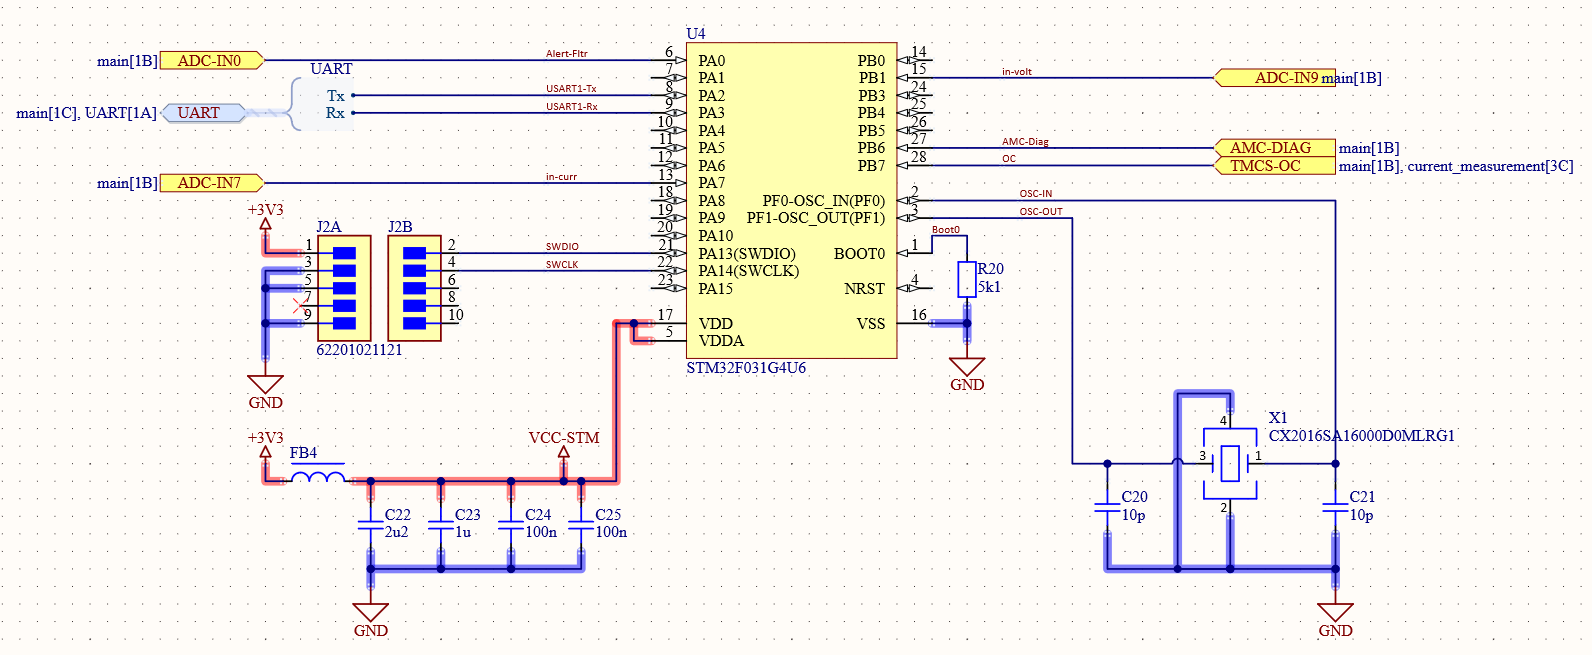
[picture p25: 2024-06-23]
photos/uc.png

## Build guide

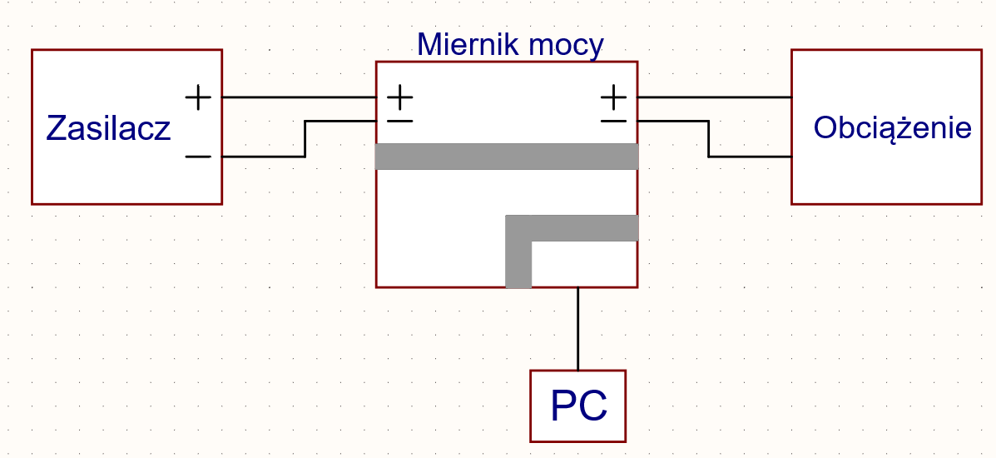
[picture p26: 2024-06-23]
photos/setup.png

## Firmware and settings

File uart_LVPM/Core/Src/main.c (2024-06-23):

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
/* Includes ------------------------------------------------------------------*/
#include "main.h"

/* USER CODE BEGIN Includes */
#include <stdio.h>
#include <inttypes.h>
#include <string.h>
//#include <stdbool.h>

/* USER CODE END Includes */

ADC_HandleTypeDef hadc;

UART_HandleTypeDef huart1;

void SystemClock_Config(void);
static void MX_GPIO_Init(void);
static void MX_USART1_UART_Init(void);
static void MX_ADC_Init(void);
/**
  * @brief  The application entry point.
  * @retval int
  */
int main(void)
{
  /* USER CODE BEGIN 1 */

  int32_t raw_c, raw_v;
  int16_t DutyCycle;
  int32_t VoltageX10, CurrentX100;
  uint8_t OC, AMC_Diag;


  // czy to muszą byc double?
  double avg_c = 0.0;
  double avg_v = 0.0;

  uint8_t iterator = 0;

  // FOR DUTY CYCLE DETECTION


  /* USER CODE END 1 */

  /* MCU Configuration--------------------------------------------------------*/

  /* Reset of all peripherals, Initializes the Flash interface and the Systick. */
  HAL_Init();

  /* Configure the system clock */
  SystemClock_Config();

  /* Initialize all configured peripherals */
  MX_GPIO_Init();
  MX_USART1_UART_Init();
  MX_ADC_Init();
  /* USER CODE BEGIN 2 */
  HAL_ADCEx_Calibration_Start(&hadc);
//  HAL_ADC_Start(&hadc);

  /* USER CODE END 2 */

  /* Infinite loop */
  /* USER CODE BEGIN WHILE */
  while (1)
  {

	  // CURRENT MEASUREMENT
	  ADC1->CHSELR = ADC_CHSELR_CHSEL7;
	  HAL_ADC_Start(&hadc);
	  HAL_ADC_PollForConversion(&hadc, 1000);
	  raw_c = HAL_ADC_GetValue(&hadc);
	  HAL_ADC_Stop(&hadc);

	  // VOLTAGE MEASUREMENT
	  ADC1->CHSELR = ADC_CHSELR_CHSEL9;
	  HAL_ADC_Start(&hadc);
	  HAL_ADC_PollForConversion(&hadc, 1000);
	  raw_v = HAL_ADC_GetValue(&hadc);
	  HAL_ADC_Stop(&hadc);

	  // READING DUTY CYCLE OF PWM (TMCS DIAG)
	  ADC1->CHSELR = ADC_CHSELR_CHSEL0;
	  HAL_ADC_Start(&hadc);
	  HAL_ADC_PollForConversion(&hadc, 10);
	  DutyCycle = HAL_ADC_GetValue(&hadc);
	  HAL_ADC_Stop(&hadc);

	  // READING DIGITAL INPUTS OF DIAGNOSTIC MODULES
	  AMC_Diag = HAL_GPIO_ReadPin(GPIOB, GPIO_PIN_6);
	  OC = HAL_GPIO_ReadPin(GPIOB, GPIO_PIN_7);

	  // AVERAGING
	  avg_c = (avg_c * 0.6) + (raw_c * 0.4);
	  avg_v = (avg_v * 0.6) + (raw_v * 0.4);

	  // CALCULATIONS
	  VoltageX10  = ((int32_t)avg_v*33*668*2)/4096;
	  CurrentX100 = (((int32_t)avg_c*3300*100/4096)-165000)*20;

	  iterator++;

	  if(iterator==255)
	  {

		  /* VOLTAGE DEBUG */
//		  char msg1[64];
//		  sprintf(msg1, "raw_v:%" PRIi32 "; voltage:%" PRIi32" \r\n", raw_v, VoltageX10);
//		  HAL_UART_Transmit(&huart1, (uint8_t*)msg1, strlen(msg1), HAL_MAX_DELAY);


		  /* CURRENT DEBUG */
//		  char msg2[64];
//		  sprintf(msg1, "raw_c:%" PRIi32 "; voltage:%" PRIi32" \r\n", rawC, VoltageX10);
//		  HAL_UART_Transmit(&huart1, (uint8_t*)msg2, strlen(msg2), HAL_MAX_DELAY);


		  /* DEFAULT TRANSMISSION */
		  VoltageX10 = 0;
		  char msg[64];
		  sprintf(msg, "%" PRIi32 ";%" PRIi32 ";%u;%u;%" PRIi16 "\r\n", VoltageX10,CurrentX100,(unsigned)OC,(unsigned)AMC_Diag,DutyCycle);
		  HAL_UART_Transmit(&huart1, (uint8_t*)msg, strlen(msg), HAL_MAX_DELAY);


		  iterator = 0;
	  }




    /* USER CODE END WHILE */

    /* USER CODE BEGIN 3 */
  }
  /* USER CODE END 3 */
}

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


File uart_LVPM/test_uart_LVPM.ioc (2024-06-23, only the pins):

Mcu.UserName=STM32F031G4Ux
PA0.Signal=ADC_IN0
PA13.Signal=SYS_SWDIO
PA14.Signal=SYS_SWCLK
PA2.Signal=USART1_TX
PA3.Signal=USART1_RX
PA7.Signal=ADC_IN7
PB1.Signal=ADC_IN9
PB5.Signal=GPIO_Input
PB6.Signal=GPIO_Input
PF0-OSC_IN.Signal=RCC_OSC_IN
PF1-OSC_OUT.Signal=RCC_OSC_OUT

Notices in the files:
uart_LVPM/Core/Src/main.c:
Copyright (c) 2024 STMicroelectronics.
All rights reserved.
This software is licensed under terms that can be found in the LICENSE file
